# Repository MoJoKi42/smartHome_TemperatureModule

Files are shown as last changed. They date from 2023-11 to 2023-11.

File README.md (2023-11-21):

# smartHome_TemperatureModule
Temperature module for my smart home project based on a **ATmega324PB**. It can be powered by one/two 18650 BatteryCell or USB-C. If you use the battery, there is also a small PV charging circuit that makes battery replacement unnecessary.
Data communication works over the **433 Mhz band** with the RFM69 module soldered to the board.

Measurements can be taken every 8 seconds (or multiples thereof). There are also two sensor options on board. One option is the **SHT41** I2C digital temperature and humidity sensor from Sensirion. The other option is a standard 100R **NTC resistor** (in my case 44001RC) powered by a constant current source. The measurement is done with a differential ADC.

*keep in mind*: The firmware is still under development. Some changes need to be made to the data header for transmission.

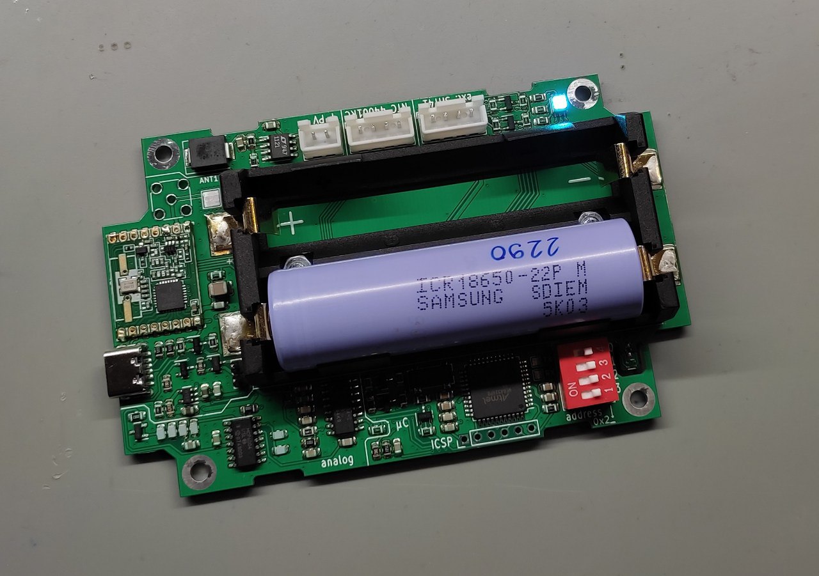
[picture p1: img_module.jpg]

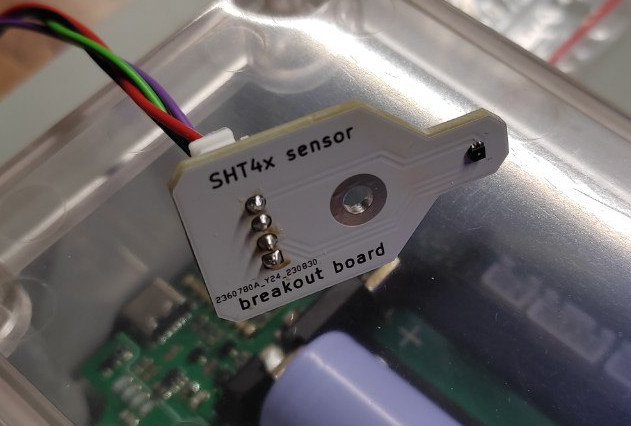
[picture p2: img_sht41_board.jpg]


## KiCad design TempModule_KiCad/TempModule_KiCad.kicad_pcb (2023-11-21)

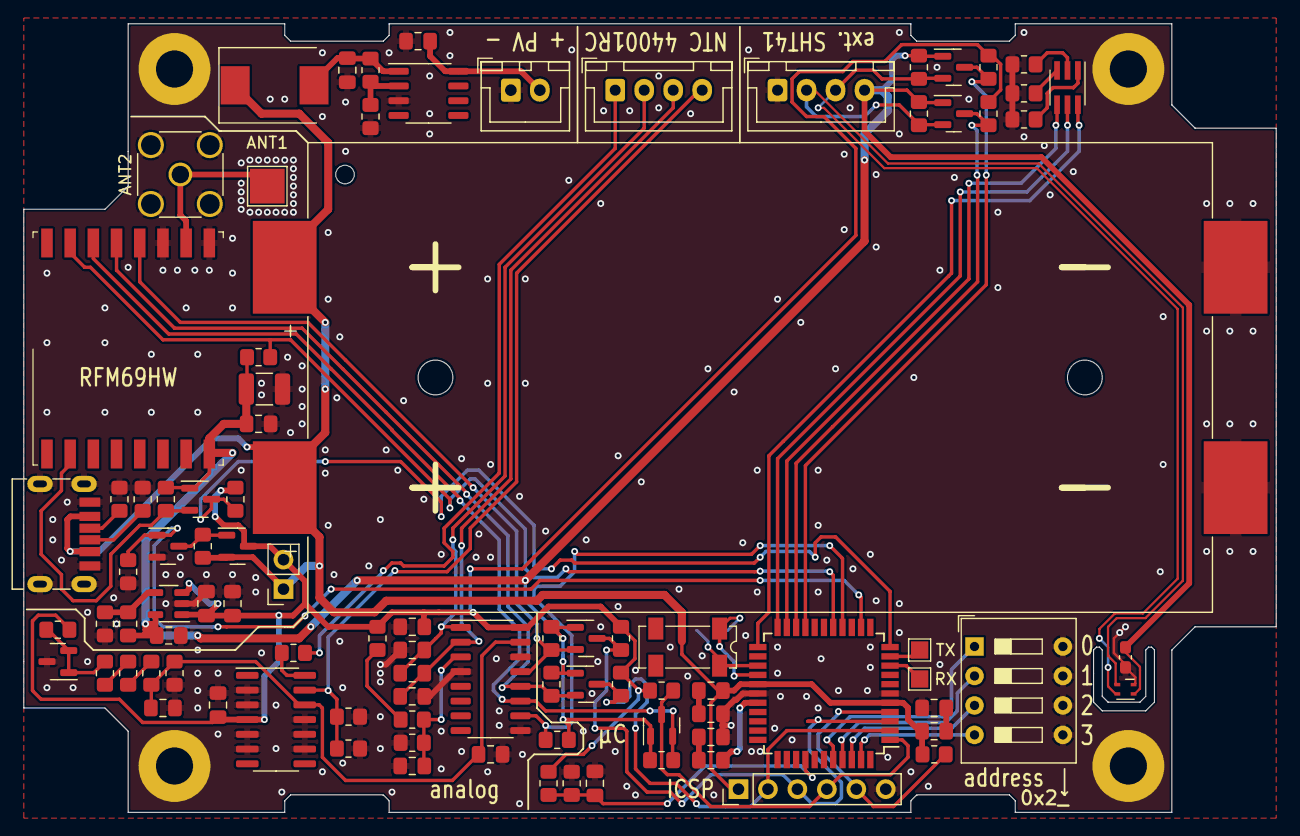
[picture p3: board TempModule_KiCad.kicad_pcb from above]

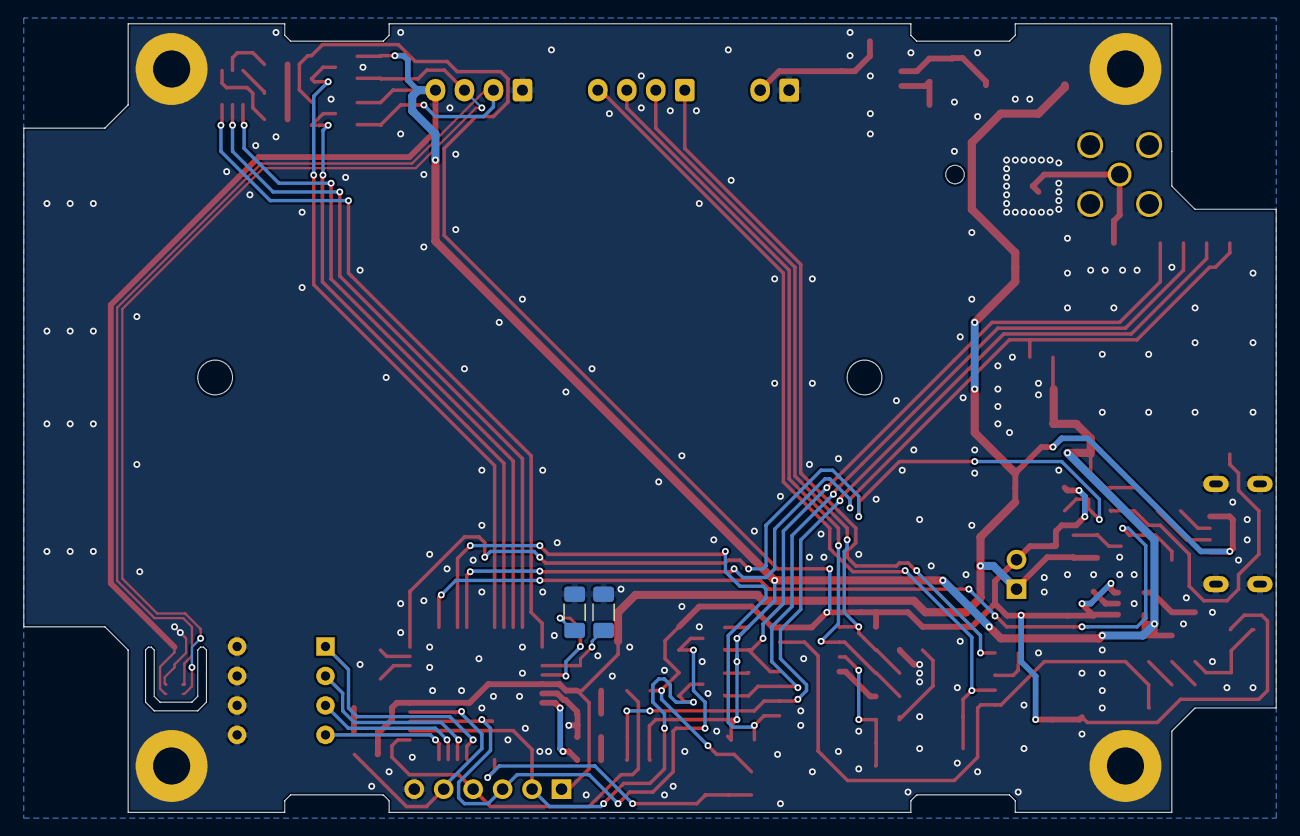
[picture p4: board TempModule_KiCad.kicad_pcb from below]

Board: 2 copper layers, 108.0 x 68.0 mm, 99 parts (2 on the bottom side), 58 nets.

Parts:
ANT1: ext. cable ANT; TestPoint_Pad_3.0x3.0mm
ANT2: SMA_connector; SMA_Wurth_60312002114503_Vertical
BATT1: 18650_SMD_Holder_2x
C1, C3, C5, C7, C8, C11, C12, C13, C15, C16, C17, C22, C23: 100n; C_0805_2012Metric_Pad1.18x1.45mm_HandSolder
C2: 10µ 16V; C_1210_3225Metric_Pad1.33x2.70mm_HandSolder
C4, C6: 2.2µ; C_0805_2012Metric_Pad1.18x1.45mm_HandSolder
C9, C14, C18, C19, C20, C21: 330n; C_0805_2012Metric_Pad1.18x1.45mm_HandSolder
C10: 100n; C_0603_1608Metric_Pad1.08x0.95mm_HandSolder
C24, C25: 15pF 1206; C_1206_3216Metric_Pad1.33x1.80mm_HandSolder
D1: VS-30BQ060; D_SMC
D2: ASMT-YTB2-0BB02; LED_Avago_PLCC6_3x2.8mm
J2: always_on_jumper; PinSocket_1x02_P2.54mm_Vertical
J3: 44001RC NTC; JST_XH_B4B-XH-A_1x04_P2.50mm_Vertical
J4: ICSP; PinHeader_1x06_P2.54mm_Vertical
J5: ext. SHT41; JST_XH_B4B-XH-A_1x04_P2.50mm_Vertical
J6: PV_Panel; JST_XH_B2B-XH-A_1x02_P2.50mm_Vertical
Q1: FDN306P; SOT-23
Q2: BSS138P; SOT-23
Q3, Q4, Q5, Q6, Q7, Q8: BSS138; SOT-23
R1, R4: 100k; R_0805_2012Metric_Pad1.20x1.40mm_HandSolder
R2, R8: 200R; R_0805_2012Metric_Pad1.20x1.40mm_HandSolder
R3, R5, R9, R10, R11, R12: 1k 0.5%; R_0805_2012Metric_Pad1.20x1.40mm_HandSolder
R6: 6.2k; R_0805_2012Metric_Pad1.20x1.40mm_HandSolder
R7, R16, R18, R19, R25, R26, R27, R28, R29, R30, R31, R32, R33, R34, R35, R36, R39: 10k; R_0805_2012Metric_Pad1.20x1.40mm_HandSolder
R13: 2k2; R_0805_2012Metric_Pad1.20x1.40mm_HandSolder
R14: 6k8; R_0805_2012Metric_Pad1.20x1.40mm_HandSolder
R15: 1k; R_0805_2012Metric_Pad1.20x1.40mm_HandSolder
R17: 47k; R_0805_2012Metric_Pad1.20x1.40mm_HandSolder
R20: 30k; R_0805_2012Metric_Pad1.20x1.40mm_HandSolder
R21: 7.5k; R_0805_2012Metric_Pad1.20x1.40mm_HandSolder
R22, R23, R24: 680R; R_0805_2012Metric_Pad1.20x1.40mm_HandSolder
R37, R38: 5.1k; R_0805_2012Metric_Pad1.20x1.40mm_HandSolder
SW1: SW_DIP_x04; SW_DIP_SPSTx04_Slide_9.78x12.34mm_W7.62mm_P2.54mm
TP2: TX; TestPoint_Pad_1.5x1.5mm
TP3: RX; TestPoint_Pad_1.5x1.5mm
U1: MCP6004; SO-14_3.9x8.65mm_P1.27mm
U2: RFM69HW; HOPERF_RFM69HW
U3: AP2210-ADJ; SOT-23-5
U4: TL432DBZ; SOT-23
U5: SHT41-AD1F-R2; Sensirion_DFN-4_1.5x1.5mm_P0.8mm_SHT4x_NoCentralPad
U6: LT1121CS8; SO-8_3.9x4.9mm_P1.27mm
U7: MCP3304; SO-16_3.9x9.9mm_P1.27mm
U8: ATmega324PB-A; TQFP-44_10x10mm_P0.8mm
U9: USB-C_6Pin_C2689837
U10, U11, U12, U13: Screw; Via_ScrewHole_3mm
Y1: Crystal_32.768_kHz; Crystal_SMD_SeikoEpson_MC306-4Pin_8.0x3.2mm

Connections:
+3.3V: C1.2, C2.1, C6.1, C10.2, J5.4, Q3.1 (G), Q4.1 (G), Q5.1 (G), Q6.1 (G), Q7.1 (G), Q8.1 (G), R6.1, R18.2, R19.2, R25.1, R27.1, R29.1, R31.1, R33.1, R35.1, U2.8 (3.3V), U3.5 (VOUT), U5.3 (VDD)
+BATT: BATT1.1 (+), C20.2, C21.2, D1.1 (K), J2.1, J4.1, Q1.2 (S), R1.1, R39.1, U8.5 (VCC), U8.27 (AVCC), U9.A9 (VBUS), U9.B9 (VBUS)
/A+: C11.2, C12.1, J3.2, U7.1 (CH0)
/A-: C12.2, C13.1, J3.3, U7.2 (CH1)
/SCL_3.3V: J5.3, Q7.2 (S), R33.2, U5.2 (SCL)
/SDA_3.3V: J5.2, Q8.2 (S), R35.2, U5.1 (SDA)
/U_Ref_0.625V: C7.1, C23.2, R11.2, R12.1, U1.12 (+), U7.15 (VREF)
/U_Ref_2.5V: R8.2, R9.1, U4.1 (REF), U4.2 (K)
/µC_unit/LED_B: D2.6 (AB), U8.23 (PC4)
/µC_unit/LED_G: D2.5 (AG), U8.22 (PC3)
/µC_unit/LED_R: D2.4 (AR), U8.21 (PC2)
/µC_unit/MISO: J4.2, Q4.3 (D), R28.1, U8.2 (PB6)
/µC_unit/MOSI: J4.4, Q5.3 (D), R30.1, U8.1 (PB5)
/µC_unit/RESET: J4.5, R39.2, U8.4 (~RESET)
/µC_unit/RFM_INT: Q6.3 (D), R32.1, U8.11 (PD2)
/µC_unit/RX: TP3.1, U8.9 (PD0)
/µC_unit/SCK: J4.3, Q3.3 (D), R26.1, U8.3 (PB7)
/µC_unit/TX: TP2.1, U8.10 (PD1)
CS_ADC_3.3V: R19.1, U7.10 (CS/SHDN), U8.15 (PD6)
CS_RFM_3.3V: R18.1, U2.15 (NSS), U8.16 (PD7)
GND: ANT2.2 (Ext), BATT1.2 (-), C1.1, C2.2, C3.1, C4.2, C5.2, C6.2, C7.2, C8.2, C9.1, C10.1, C11.1, C13.2, C14.1, C15.2, C16.1, C18.1, C19.1, C22.2, C23.1, C24.2, C25.2, J4.6, J5.1, J6.1, Q2.2 (S), R3.2, R4.2, R5.2, R7.2, R12.2, R15.2, R17.2, R21.2, R22.2, R23.2, R24.2, R37.2, R38.2, SW1.5, SW1.6, SW1.7, SW1.8, U1.2 (-), U1.3 (+), U1.5 (+), U1.6 (-), U1.9 (-), U1.10 (+), U1.11 (V-), U2.9 (GND), U2.11 (GND), U3.2 (GND), U4.3 (A), U5.4 (VSS), U6.3 (GND), U7.4 (CH3), U7.9 (DGND), U7.14 (AGND), U8.6 (GND), U8.28 (GND), U9.A12 (GND), U9.B12 (GND), U9.SHIELD, U10.1, U11.1, U12.1, U13.1
MISO_3.3V: Q4.2 (S), R27.2, U2.13 (MISO), U7.12 (DOUT)
MOSI_3.3V: Q5.2 (S), R29.2, U2.14 (MOSI), U7.11 (DIN)
unnamed: ANT1.1, ANT2.1 (In), U2.10 (ANA)
unnamed: C8.1, R14.2, R15.1, U7.3 (CH2)
unnamed: C9.2, J6.2, U6.8 (IN)
unnamed: C14.2, D1.2 (A), R16.1, U6.1 (OUT)
unnamed: C16.2, C17.1
unnamed: C17.2, U8.29 (PE4/AREF)
unnamed: C18.2, C20.1
unnamed: C19.2, C21.1
unnamed: C22.1, R20.2, R21.1, U8.37 (PA0)
unnamed: C24.1, U8.26 (PC7), Y1.1
unnamed: C25.1, U8.25 (PC6), Y1.4
unnamed: D2.1 (KB), R22.1
unnamed: D2.2 (KG), R23.1
unnamed: D2.3 (KR), R24.1
unnamed: J3.1, R2.2
unnamed: J3.4, R3.1, R5.1, U1.13 (-)
unnamed: Q1.1 (G), Q2.3 (D), R1.2
unnamed: R2.1, U1.14
unnamed: R6.2, R7.1, U3.4 (ADJ)
unnamed: R9.2, R10.1
unnamed: R10.2, R11.1
unnamed: R13.2, R14.1
unnamed: R16.2, R17.1, U6.2 (ADJ)
unnamed: R37.1, U9.B5 (VCONN)
unnamed: R38.1, U9.A5 (CC)
unnamed: SW1.1, U8.40 (PB0)
unnamed: SW1.2, U8.41 (PB1)
unnamed: SW1.3, U8.42 (PB2)
unnamed: SW1.4, U8.43 (PB3)
Power_on: Q2.1 (G), R4.1, U8.13 (PD4)
RFM_INT_3.3V: Q6.2 (S), R31.2, U2.2 (DIO0)
SCK_3.3V: Q3.2 (S), R25.2, U2.12 (SCK), U7.13 (CLK)
SCL: Q7.3 (D), R34.1, U8.19 (PC0)
SDA: Q8.3 (D), R36.1, U8.20 (PC1)
VCC: C3.2, C4.1, C5.1, C15.1, J2.2, Q1.3 (D), R8.1, R13.1, R20.1, R26.2, R28.2, R30.2, R32.2, R34.2, R36.2, U1.4 (V+), U3.1 (VIN), U3.3 (EN), U7.16 (VDD)

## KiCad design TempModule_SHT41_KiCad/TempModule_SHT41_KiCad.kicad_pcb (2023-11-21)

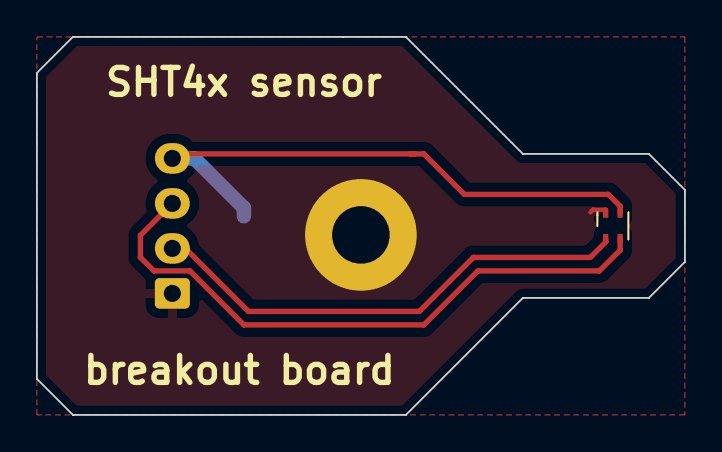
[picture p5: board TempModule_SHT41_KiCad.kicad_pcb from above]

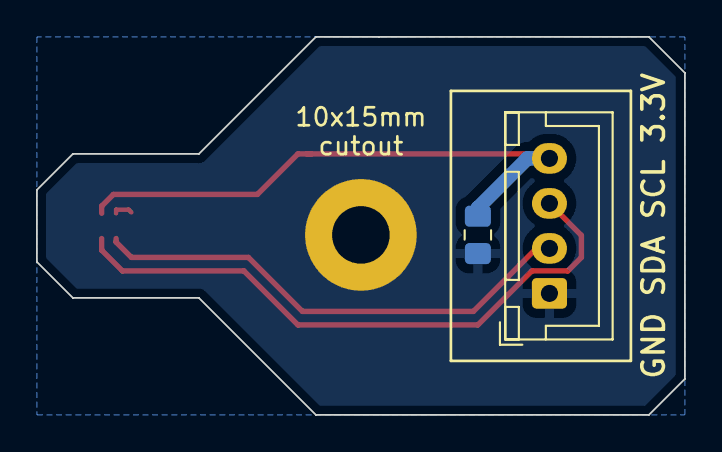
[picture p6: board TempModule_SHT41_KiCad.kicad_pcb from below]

Board: 2 copper layers, 36.0 x 21.0 mm, 4 parts (2 on the bottom side), 4 nets.

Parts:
C1: 100n; C_0805_2012Metric_Pad1.18x1.45mm_HandSolder
J1: ext. SHT41; JST_XH_B4B-XH-A_1x04_P2.50mm_Vertical
U1: Screw; Via_ScrewHole_3mm
U2: SHT41-AD1F-R2; Sensirion_DFN-4_1.5x1.5mm_P0.8mm_SHT4x_NoCentralPad

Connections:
+3.3V: C1.2, J1.4, U2.3 (VDD)
/SCL_3.3V: J1.3, U2.2 (SCL)
/SDA_3.3V: J1.2, U2.1 (SDA)
GND: C1.1, J1.1, U1.1, U2.4 (VSS)

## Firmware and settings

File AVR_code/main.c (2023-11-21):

#include <avr/io.h>
#include <avr/interrupt.h>
#include <avr/sleep.h>
#include <util/delay.h>
#include <stdio.h>
#include <stdlib.h>
#include <math.h>
#include <time.h>
#include "radio.h"
#include "twi.h"
#include "RFM69.h"
#include "RFM69registers.h"
#include "sht4x.h"
#include "adc.h"

// Commands :
//
// -> Compile
// make all
//
// -> Flashing
// avrdude -p m324pb -c usbasp -e -U flash:w:main.hex
// avrdude -p m324pb -c dragon_isp -e -U flash:w:main.hex
//
// -> Write Fuses
// avrdude -c usbasp -p m324pb -U lfuse:w:0x42:m -U hfuse:w:0xD9:m -U efuse:w:0xFF:m
// avrdude -c dragon_isp -p m324pb -U lfuse:w:0x42:m -U hfuse:w:0xD9:m -U efuse:w:0xFF:m
//
// -> VS Code Include Pfad
// "/usr/lib/avr/include"
//

// Port definitions
#define LED_R_off    PORTC &= ~(1<<PC2)
#define LED_R_on     PORTC |=  (1<<PC2)
#define LED_G_off    PORTC &= ~(1<<PC3)
#define LED_G_on     PORTC |=  (1<<PC3)
#define LED_B_off    PORTC &= ~(1<<PC4)
#define LED_B_on     PORTC |=  (1<<PC4)

#define PowerON      PORTD |=  (1<<PD4)
#define PowerOFF     PORTD &= ~(1<<PD4)

#define CS_ADC_en    DDRD |=  (1<<PD6)
#define CS_ADC_dis   DDRD &=  ~(1<<PD6)
#define CS_RFM_en    DDRD |=  (1<<PD7)  // see "RFM69.h" on line 39
#define CS_RFM_dis   DDRD &=  ~(1<<PD7) // see "RFM69.h" on line 39


// Prototypes
void sleep_init(void);
void sleep_start(uint16_t duration);


// RFM69 definitions
#define MaxRetries          1
#define MaxRetryWaitTime    250  // max 250ms  
#define NETWORKID           33
const char EncryptKey[16] = "1234567812345678";
uint8_t    deviceID       = 0x20;
uint8_t    baseID         = 0x01;   // ID of base station



// ToDo:
// - Datenheader anpassen
// - Schauen welche Delays verkürzt werden können!



int main(void) {

    // Outputs
    DDRC  |= (1<<PC2)|(1<<PC3)|(1<<PC4);            // Output LEDs
    DDRD  |= (1<<PD4);                              // Output PowerON Pin
    PORTB |= (1<<PB0)|(1<<PB1)|(1<<PB2)|(1<<PB3);   // Enable Address PullUps
    CS_ADC_dis;
    CS_RFM_dis;
    
    PowerON;
    _delay_ms(200);
    
    // get DeviceID 
    deviceID |= (~PINB & 0x0F);
    if (deviceID == 0x20) {
        while(1) {
            LED_R_on;       // address 0x20 not allowed!
            _delay_ms(200);
            LED_R_off;
            _delay_ms(200);
        }
    }
    
    // init Sleep
    sleep_init();
    
    
    while (1) {
        
        // enable LED
        LED_B_on;
        
        // init RFM69
        rfm69_init(433, deviceID, NETWORKID);
        setHighPower(1);    // if model number rfm69hw
        setPowerLevel(30);  // 0-31; 5dBm to 20 dBm
        encrypt(EncryptKey);
        
        // init SHT41
        sht4x_init_twi();
        
        // measurement SHT41
        sht4x_send_cmd(0xFD);
        _delay_ms(200);
        uint8_t data[6];
        float temperature;
        float humidity;
        if (sht4x_read_data(data)) {
            temperature =  0.0;   // got invalid data
            humidity = 0.0;       // got invalid data
        } else {
            temperature =  sht4x_get_temperature_from_data(data);
            humidity =     sht4x_get_humidity_from_data(data);
        }
        
        // measurement batteryVoltage
        adc_init();
        float batteryVoltage = adc_read_avg(0, 10);
        batteryVoltage = batteryVoltage * (5.0 * 1.1 / 1023.0);
        
        
        // generate json string
        char str[200];
        sprintf(str, "{\"deviceID_hex\":%x,\"uptime\":%d,\"batteryVoltage\":%0.3f,\"temperature\":%0.2f,\"humidity\":%0.2f}",
                         deviceID,           0,            batteryVoltage,          temperature,          humidity);
        
        
        // get number of single packets
        uint16_t data_length = strlen(str);
        uint8_t MAX_DATA_LEN = RF69_MAX_DATA_LEN - RADIO_HEADER_LEN;
        uint8_t packet_cnt = data_length/MAX_DATA_LEN;
        if (data_length % MAX_DATA_LEN)
            packet_cnt++;
        
        // send packets
        uint8_t successful_transmitted = 1;
        for (int packet=0; packet < packet_cnt; packet++) {
            
            // calculate packet length
            uint8_t packet_lenght;
            if (packet == packet_cnt-1 && data_length % MAX_DATA_LEN) {
                packet_lenght = data_length % MAX_DATA_LEN;
            } else {
                packet_lenght = MAX_DATA_LEN;
            }
            
            // add data header
            uint8_t buffer[RF69_MAX_DATA_LEN];
            uint8_t buffer_len = radio_generate_header(buffer, str + (packet*MAX_DATA_LEN), packet_lenght, packet, packet_cnt, RADIO_DATATYPE_MQTT_JSON, deviceID, baseID);
        
            // send data
            uint8_t statusACK = 0;
            uint8_t retry = 0; uint8_t timeRetry = 0;
            while (retry < MaxRetries) {
                
                // send
                send(baseID, buffer, buffer_len, 1);
                
                // check ACK + wait
                timeRetry = 0;
                while (timeRetry < MaxRetryWaitTime) {
                    statusACK = ACKReceived(baseID);
                    if (statusACK) { break; }
                    _delay_ms(1);
                    timeRetry++;
                }
                
                // abort next retry when ACK received
                if (statusACK) { break; }
                retry++;
            }
            
            // reset "successful_transmitted"-variable when one ACK is missing
            if (!statusACK)
                successful_transmitted = 0;
        }
        
        // power off
        PowerOFF;
        
        // show ACK/NACK with LEDs
        LED_B_off;
        if (successful_transmitted) {
            LED_G_on;
        } else {
            LED_R_on;
        }
        _delay_ms(100);
        LED_R_off;
        LED_G_off;
        
        // sleep
        sleep_start(8);
        PowerON;
        _delay_ms(100);
    }
    
}


////////////////////////////////////////////////////////////////////////////////////////////
// sleep functions
////////////////////////////////////////////////////////////////////////////////////////////

// init sleep registers
void sleep_init(void) {
    
    ASSR = (1<<AS2);                                // select asynchronous operation of Timer2
    TCCR2A = 0x00;                                  // Normal mode
    TCCR2B = (1<<CS22) | (1<<CS21) | (1<<CS20) ;    // Prescaler = 1024
    TIMSK2 = (1<<TOIE2);                            // Timer0 overflow interrup enable
    TCNT2 =  0;                                     // Preload Value
    
    while((ASSR & (1<<OCR2AUB)) || (ASSR & (1<<OCR2BUB)));  // wait
    while((ASSR & (1<<TCR2AUB)) || (ASSR & (1<<TCR2BUB)));  // wait
    while((ASSR & (1<<TCN2UB)));                            // wait
}

// Timer2 overflow Interrupt (sleep functions)
ISR(TIMER2_OVF_vect) { }

// go sleeping function
// duration = 8...2048 seconds (in 8 seconds steps)
void sleep_start(uint16_t duration) {
    
    // set sleep duration
    uint8_t sleep_counter = 0;
    if (duration >= 2048) {
        sleep_counter = 255;
    } else {
        sleep_counter = duration / 8;
    }
    
    sei();                                  // enable interrups
    for (int i=0; i<sleep_counter; i++) {
        set_sleep_mode(SLEEP_MODE_PWR_SAVE);    // set sleep mode
        sleep_mode();                           // go sleeping
    }
    cli();                                  // disable intrrups
}

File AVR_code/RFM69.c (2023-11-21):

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
// Licence can be viewed at                               
// http://www.gnu.org/licenses/gpl-3.0.txt
//
// Please maintain this license information along with authorship
// and copyright notices in any redistribution of this code
// **********************************************************************************
// https://github.com/nayem-cosmic/RFM69-Library-AVR/tree/master
// **********************************************************************************
// Converted to AVR environment by Zulkar Nayem
// **********************************************************************************


#include <avr/io.h>
#include <avr/interrupt.h>
#include "spi.h"
#include "RFM69registers.h"
#include "RFM69.h"
#include "get_millis.h"

volatile uint8_t DATALEN;
volatile uint8_t SENDERID;
volatile uint8_t TARGETID;                 // should match _address
volatile uint8_t PAYLOADLEN;
volatile uint8_t ACK_REQUESTED;
volatile uint8_t ACK_RECEIVED;             // should be polled immediately after sending a packet with ACK request
volatile int16_t RSSI;                     // most accurate RSSI during reception (closest to the reception)
volatile uint8_t mode = RF69_MODE_STANDBY; // should be protected?
volatile uint8_t inISR = 0; 
uint8_t isRFM69HW = 1;                     // if RFM69HW model matches high power enable possible
uint8_t address;                           //nodeID
uint8_t powerLevel = 31;
uint8_t promiscuousMode = 0;
unsigned long millis_current;

// freqBand must be selected from 315, 433, 868, 915
void rfm69_init(uint16_t freqBand, uint8_t nodeID, uint8_t networkID)
{
    const uint8_t CONFIG[][2] =
    {
        /* 0x01 */ { REG_OPMODE, RF_OPMODE_SEQUENCER_ON | RF_OPMODE_LISTEN_OFF | RF_OPMODE_STANDBY },
        /* 0x02 */ { REG_DATAMODUL, RF_DATAMODUL_DATAMODE_PACKET | RF_DATAMODUL_MODULATIONTYPE_FSK | RF_DATAMODUL_MODULATIONSHAPING_00 }, // no shaping
        /* 0x03 */ { REG_BITRATEMSB, RF_BITRATEMSB_55555}, // default: 4.8 KBPS
        /* 0x04 */ { REG_BITRATELSB, RF_BITRATELSB_55555},
        /* 0x05 */ { REG_FDEVMSB, RF_FDEVMSB_50000}, // default: 5KHz, (FDEV + BitRate / 2 <= 500KHz)
        /* 0x06 */ { REG_FDEVLSB, RF_FDEVLSB_50000},

        //* 0x07 */ { REG_FRFMSB, RF_FRFMSB_433},
        //* 0x08 */ { REG_FRFMID, RF_FRFMID_433},
        //* 0x09 */ { REG_FRFLSB, RF_FRFLSB_433},
        
        /* 0x07 */ { REG_FRFMSB, (uint8_t) (freqBand==RF_315MHZ ? RF_FRFMSB_315 : (freqBand==RF_433MHZ ? RF_FRFMSB_433 : (freqBand==RF_868MHZ ? RF_FRFMSB_868 : RF_FRFMSB_915))) },
        /* 0x08 */ { REG_FRFMID, (uint8_t) (freqBand==RF_315MHZ ? RF_FRFMID_315 : (freqBand==RF_433MHZ ? RF_FRFMID_433 : (freqBand==RF_868MHZ ? RF_FRFMID_868 : RF_FRFMID_915))) },
        /* 0x09 */ { REG_FRFLSB, (uint8_t) (freqBand==RF_315MHZ ? RF_FRFLSB_315 : (freqBand==RF_433MHZ ? RF_FRFLSB_433 : (freqBand==RF_868MHZ ? RF_FRFLSB_868 : RF_FRFLSB_915))) },


        // looks like PA1 and PA2 are not implemented on RFM69W, hence the max output power is 13dBm
        // +17dBm and +20dBm are possible on RFM69HW
        // +13dBm formula: Pout = -18 + OutputPower (with PA0 or PA1**)
        // +17dBm formula: Pout = -14 + OutputPower (with PA1 and PA2)**
        // +20dBm formula: Pout = -11 + OutputPower (with PA1 and PA2)** and high power PA settings (section 3.3.7 in datasheet)
        ///* 0x11 */ { REG_PALEVEL, RF_PALEVEL_PA0_ON | RF_PALEVEL_PA1_OFF | RF_PALEVEL_PA2_OFF | RF_PALEVEL_OUTPUTPOWER_11111},
        ///* 0x13 */ { REG_OCP, RF_OCP_ON | RF_OCP_TRIM_95 }, // over current protection (default is 95mA)

        // RXBW defaults are { REG_RXBW, RF_RXBW_DCCFREQ_010 | RF_RXBW_MANT_24 | RF_RXBW_EXP_5} (RxBw: 10.4KHz)
        /* 0x19 */ { REG_RXBW, RF_RXBW_DCCFREQ_010 | RF_RXBW_MANT_16 | RF_RXBW_EXP_2 }, // (BitRate < 2 * RxBw)
        //for BR-19200: /* 0x19 */ { REG_RXBW, RF_RXBW_DCCFREQ_010 | RF_RXBW_MANT_24 | RF_RXBW_EXP_3 },
        /* 0x25 */ { REG_DIOMAPPING1, RF_DIOMAPPING1_DIO0_01 }, // DIO0 is the only IRQ we're using
        /* 0x26 */ { REG_DIOMAPPING2, RF_DIOMAPPING2_CLKOUT_OFF }, // DIO5 ClkOut disable for power saving
        /* 0x28 */ { REG_IRQFLAGS2, RF_IRQFLAGS2_FIFOOVERRUN }, // writing to this bit ensures that the FIFO & status flags are reset
        /* 0x29 */ { REG_RSSITHRESH, 220 }, // must be set to dBm = (-Sensitivity / 2), default is 0xE4 = 228 so -114dBm
        ///* 0x2D */ { REG_PREAMBLELSB, RF_PREAMBLESIZE_LSB_VALUE } // default 3 preamble bytes 0xAAAAAA
        /* 0x2E */ { REG_SYNCCONFIG, RF_SYNC_ON | RF_SYNC_FIFOFILL_AUTO | RF_SYNC_SIZE_2 | RF_SYNC_TOL_0 },
        /* 0x2F */ { REG_SYNCVALUE1, 0x2D },      // attempt to make this compatible with sync1 byte of RFM12B lib
        /* 0x30 */ { REG_SYNCVALUE2, networkID }, // NETWORK ID
        /* 0x37 */ { REG_PACKETCONFIG1, RF_PACKET1_FORMAT_VARIABLE | RF_PACKET1_DCFREE_OFF | RF_PACKET1_CRC_ON | RF_PACKET1_CRCAUTOCLEAR_ON | RF_PACKET1_ADRSFILTERING_OFF },
        /* 0x38 */ { REG_PAYLOADLENGTH, 66 }, // in variable length mode: the max frame size, not used in TX
        ///* 0x39 */ { REG_NODEADRS, nodeID }, // turned off because we're not using address filtering
        /* 0x3C */ { REG_FIFOTHRESH, RF_FIFOTHRESH_TXSTART_FIFONOTEMPTY | RF_FIFOTHRESH_VALUE }, // TX on FIFO not empty
        /* 0x3D */ { REG_PACKETCONFIG2, RF_PACKET2_RXRESTARTDELAY_2BITS | RF_PACKET2_AUTORXRESTART_ON | RF_PACKET2_AES_OFF }, // RXRESTARTDELAY must match transmitter PA ramp-down time (bitrate dependent)
        //for BR-19200: /* 0x3D */ { REG_PACKETCONFIG2, RF_PACKET2_RXRESTARTDELAY_NONE | RF_PACKET2_AUTORXRESTART_ON | RF_PACKET2_AES_OFF }, // RXRESTARTDELAY must match transmitter PA ramp-down time (bitrate dependent)
        /* 0x6F */ { REG_TESTDAGC, RF_DAGC_IMPROVED_LOWBETA0 }, // run DAGC continuously in RX mode for Fading Margin Improvement, recommended default for AfcLowBetaOn=0
        {255, 0}
    };
    
    spi_init();                // spi initialize
    SS_DDR &= ~(1<<SS_PIN);
    SS_PORT &= ~(1<<SS_PIN);     // setting slave select low (prepare)
    INT_DDR &= ~(1<<INT_PIN_n);  // setting interrupt pin input. no problem if not given
    INT_PORT &= ~(1<<INT_PIN_n); // setting pull down. because rising will cause interrupt. external pull down is needed.
    
    while (readReg(REG_SYNCVALUE1) != 0xaa)
    {
        writeReg(REG_SYNCVALUE1, 0xaa);
    }

    while (readReg(REG_SYNCVALUE1) != 0x55)
    {
        writeReg(REG_SYNCVALUE1, 0x55);
    }

    for (uint8_t i = 0; CONFIG[i][0] != 255; i++)
        writeReg(CONFIG[i][0], CONFIG[i][1]);

    // Encryption is persistent between resets and can trip you up during debugging.
    // Disable it during initialization so we always start from a known state.
    encrypt(0);
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

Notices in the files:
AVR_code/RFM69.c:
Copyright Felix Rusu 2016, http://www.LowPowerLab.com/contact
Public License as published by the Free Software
